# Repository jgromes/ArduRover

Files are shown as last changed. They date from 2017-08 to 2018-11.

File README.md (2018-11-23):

# ArduRover

## Open-source, full metal 6WD robot

---

Repository contents:
* **android** - All Android control app source files.
* **apk** - Android application package file. Install on your own risk!
* **arduino/arduroverController** - USB control sketch, runs on Arduino, takes in Serial input from PC and transmits the commands to the robot via LoRenz shield.
* **arduino/arduroverControllerBluetooth** - Bluetooth control sketch, same as the above but works with bluetooth and the Android control app.
* **arduino/arduroverMain** - The on-board sketch that controls the robot, receives commands via LoRenz shield and executes them.
* **doc** - Part design files (PDF drawings and Solidworks part files).

---

Find out more about the project here:
* Part 1 - <http://www.deviceplus.com/how-tos/arduino-guide/arduino-explorer-rover-chassis-final-assembly/>
* Part 2 - <http://www.deviceplus.com/how-tos/arduino-guide/arduino-explorer-rover-part-2-electronics-wiring/>
* Part 3 - <http://www.deviceplus.com/how-tos/arduino-guide/ardurover-arduino-explorer-rover-part-3-programming/>

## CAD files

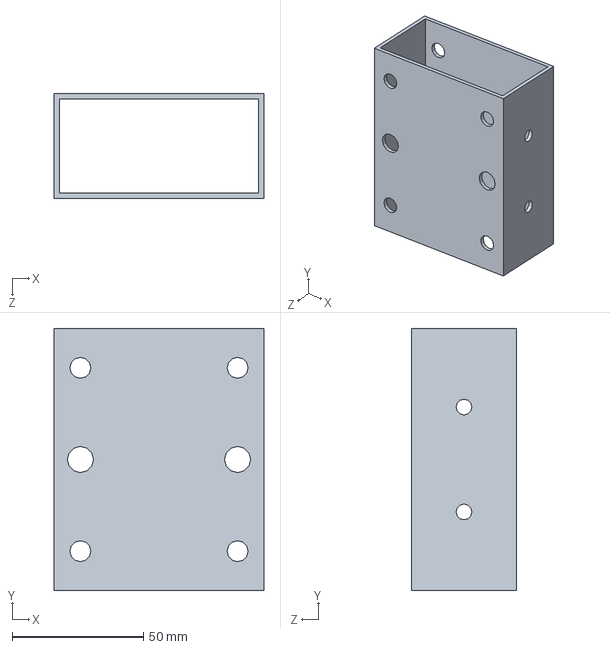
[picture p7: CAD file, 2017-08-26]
doc/sldprt/frame_block.SLDPRT
80.0 x 100.0 x 40.0 mm

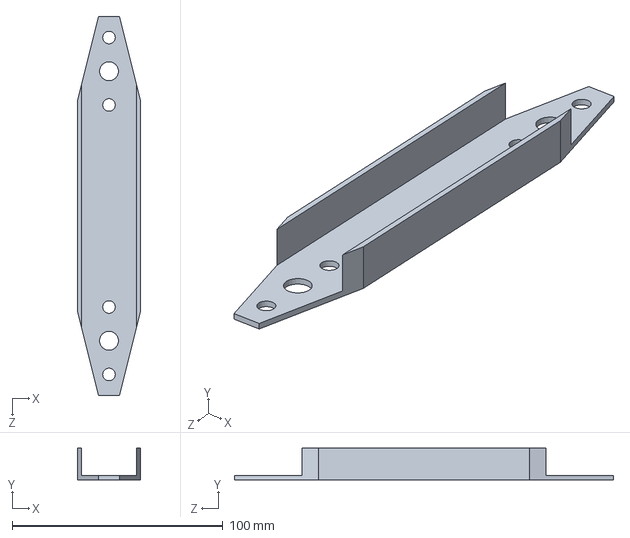
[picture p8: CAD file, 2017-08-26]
doc/sldprt/control_arm.SLDPRT
30.0 x 15.0 x 180.0 mm

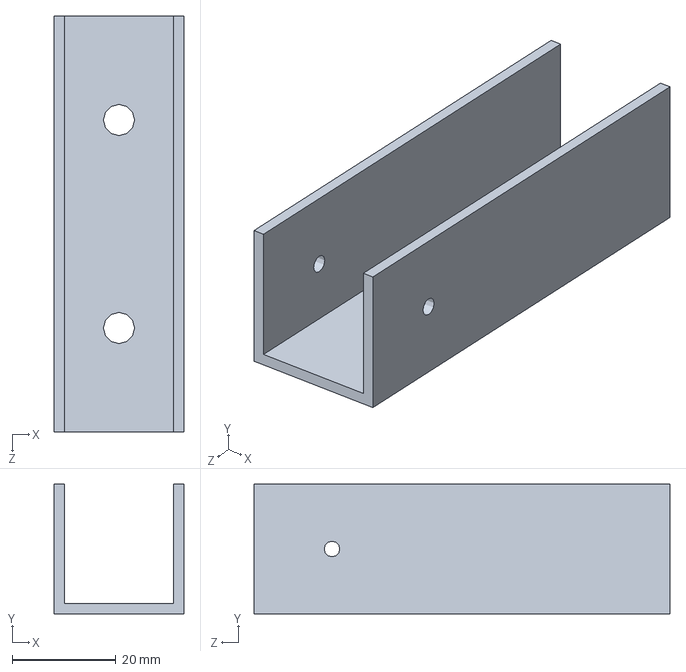
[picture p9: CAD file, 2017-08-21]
doc/sldprt/absorber_attachment_frame.SLDPRT
25.0 x 25.0 x 80.0 mm

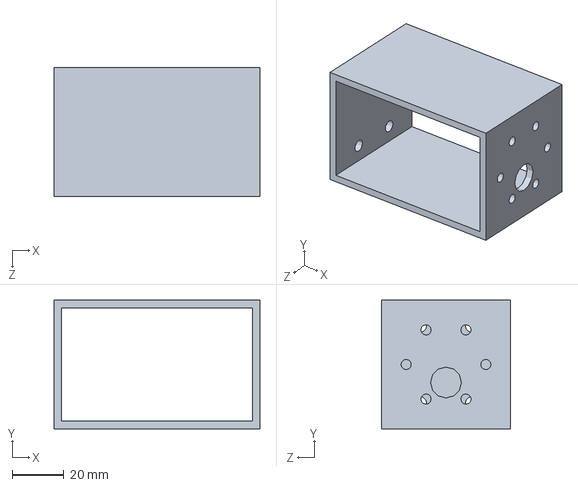
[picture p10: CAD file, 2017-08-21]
doc/sldprt/motor_block.SLDPRT
80.0 x 50.0 x 50.0 mm

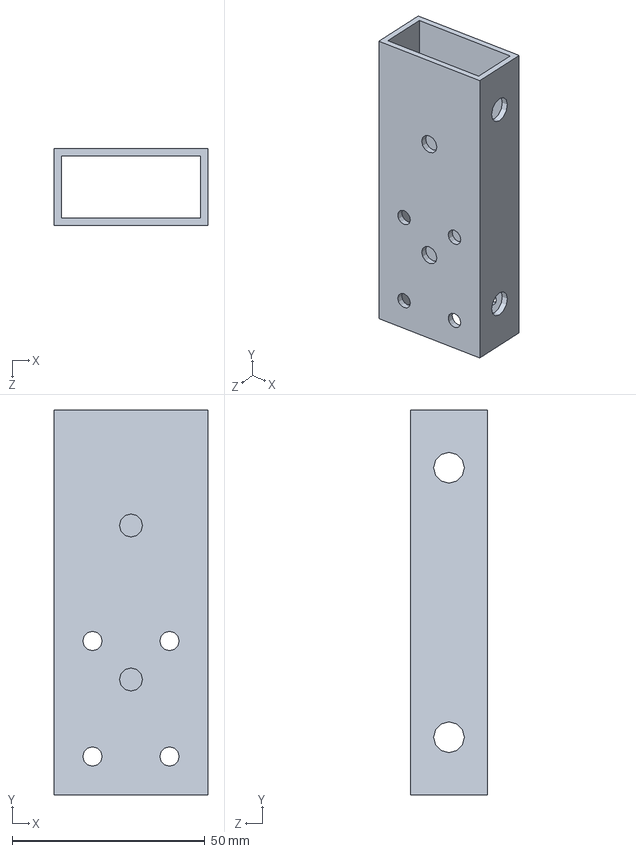
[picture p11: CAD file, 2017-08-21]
doc/sldprt/suspension_block.SLDPRT
40.0 x 100.0 x 20.0 mm

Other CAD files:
doc/sldprt/absorber_attachment_motor.SLDPRT
doc/slddrw/absorber_attachment_frame.SLDDRW
doc/slddrw/absorber_attachment_motor.SLDDRW
doc/slddrw/control_arm.SLDDRW
doc/slddrw/frame_block.SLDDRW
doc/slddrw/motor_block.SLDDRW
doc/slddrw/suspension_block.SLDDRW

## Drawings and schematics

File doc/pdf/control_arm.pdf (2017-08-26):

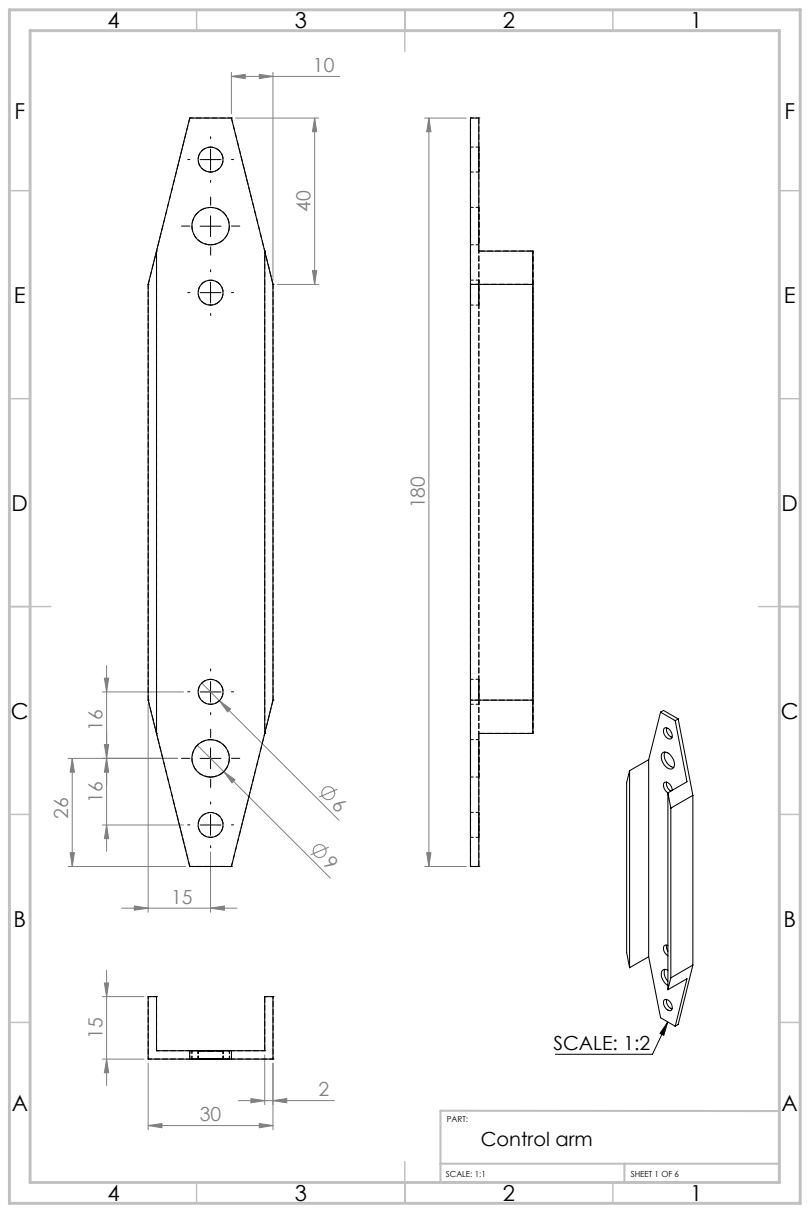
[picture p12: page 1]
SCALE: 1:2; Control arm; SCALE: 1:1; SHEET 1 OF 6

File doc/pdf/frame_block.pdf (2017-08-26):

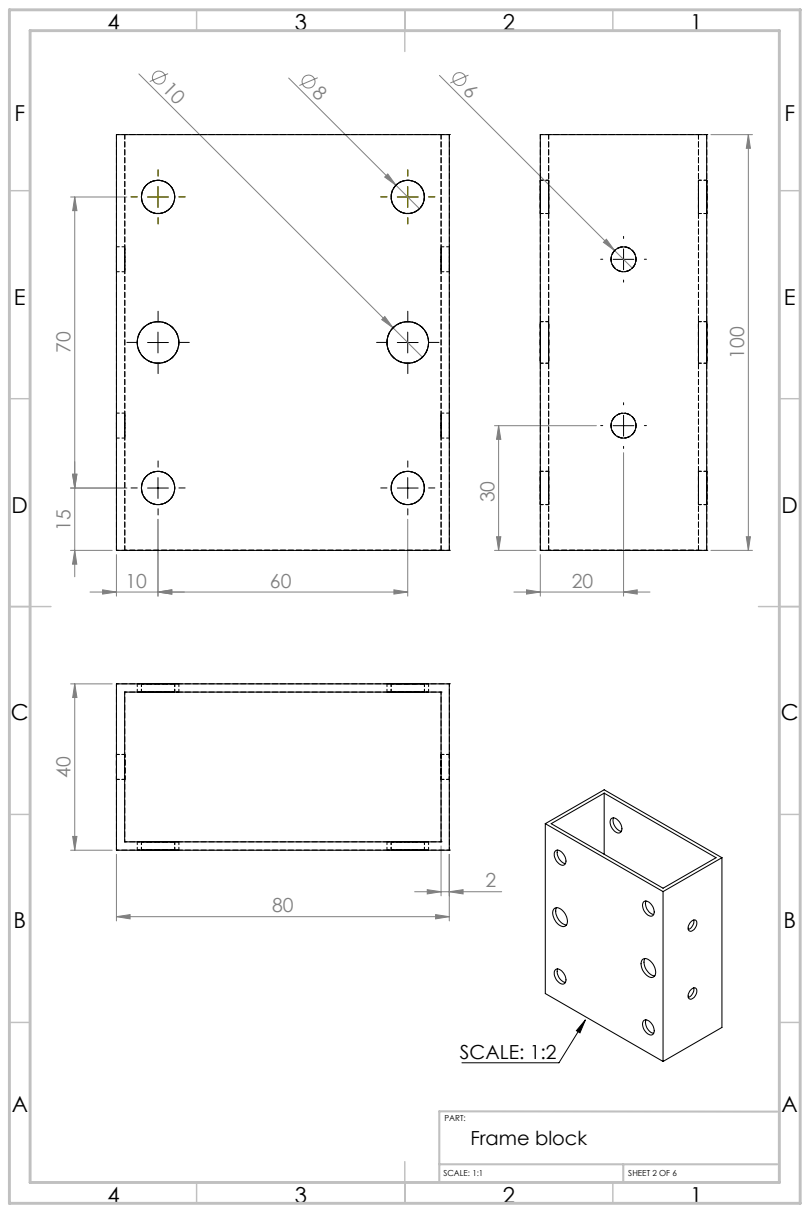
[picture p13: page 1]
SCALE: 1:2; Frame block; SCALE: 1:1; SHEET 2 OF 6

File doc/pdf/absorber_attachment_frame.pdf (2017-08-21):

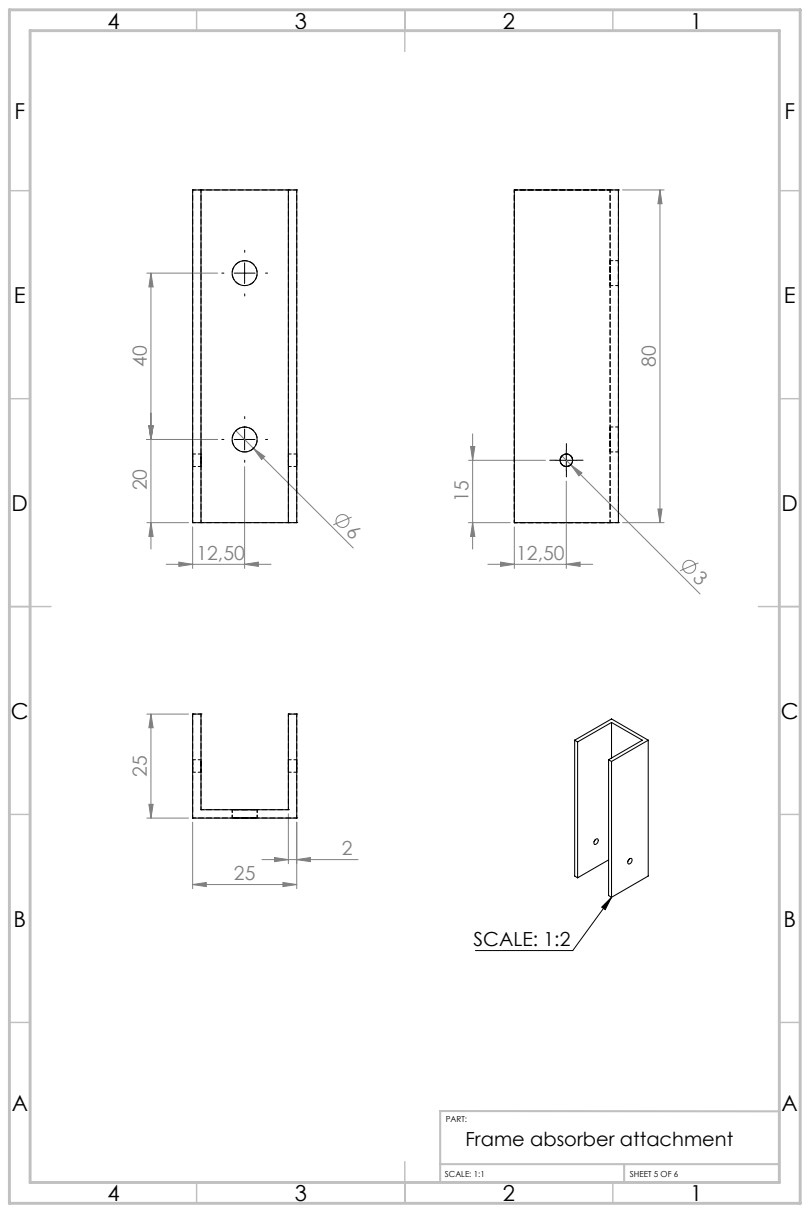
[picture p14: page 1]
SCALE: 1:2; Frame absorber attachment; SCALE: 1:1; SHEET 5 OF 6

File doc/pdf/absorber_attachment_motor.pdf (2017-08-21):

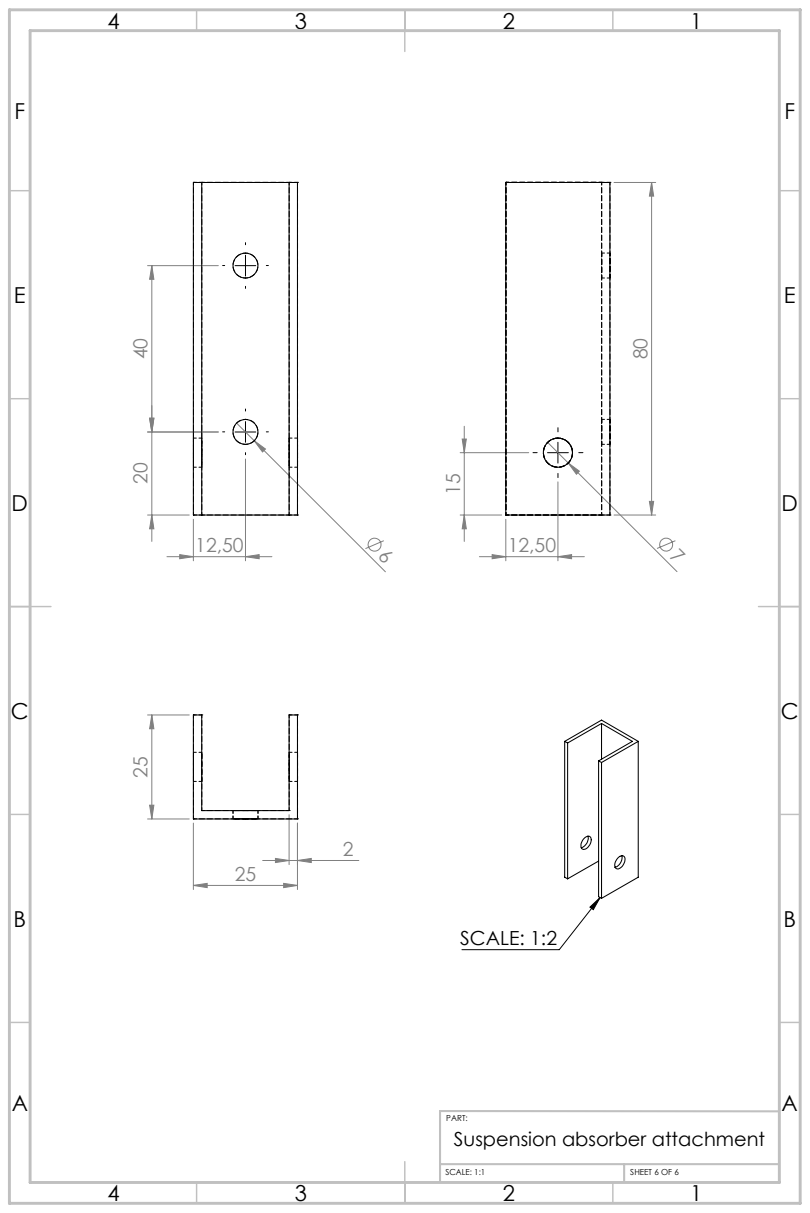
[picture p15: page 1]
SCALE: 1:2; Suspension absorber attachment; SCALE: 1:1; SHEET 6 OF 6

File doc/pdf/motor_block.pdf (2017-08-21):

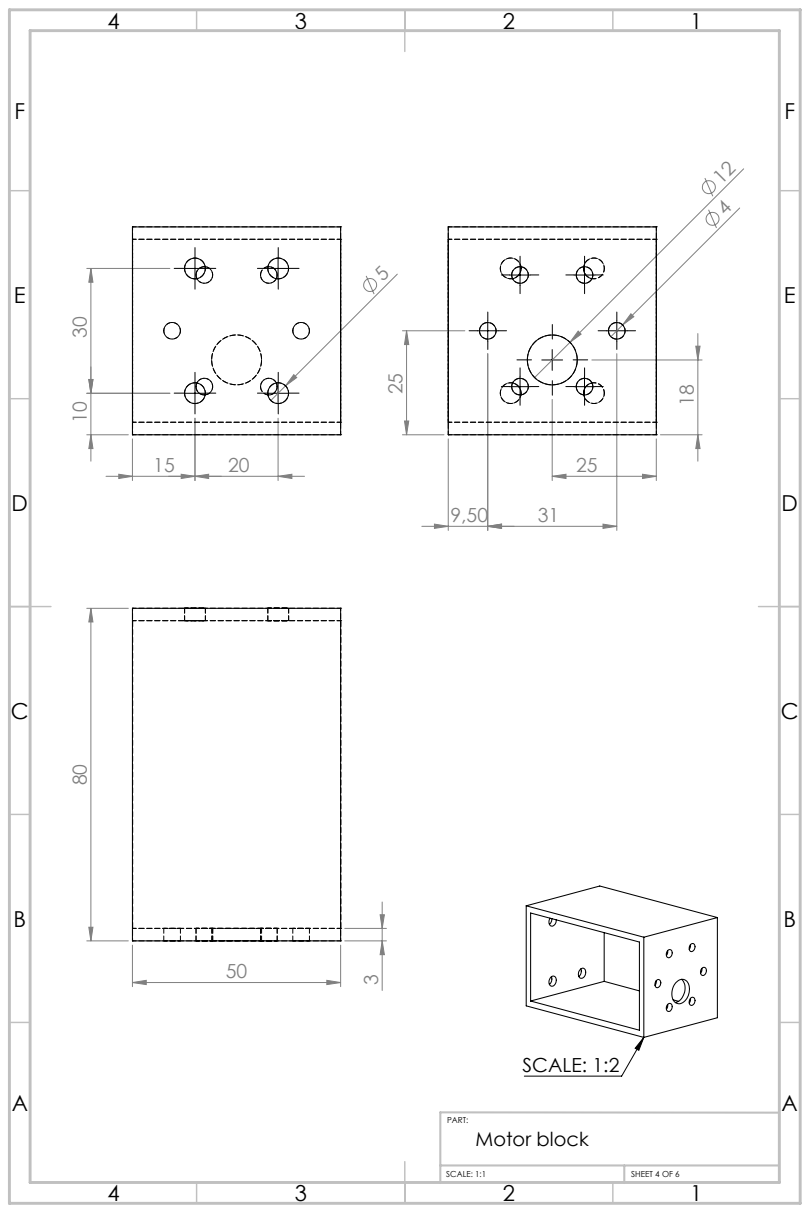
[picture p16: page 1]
SCALE: 1:2; Motor block; SCALE: 1:1; SHEET 4 OF 6

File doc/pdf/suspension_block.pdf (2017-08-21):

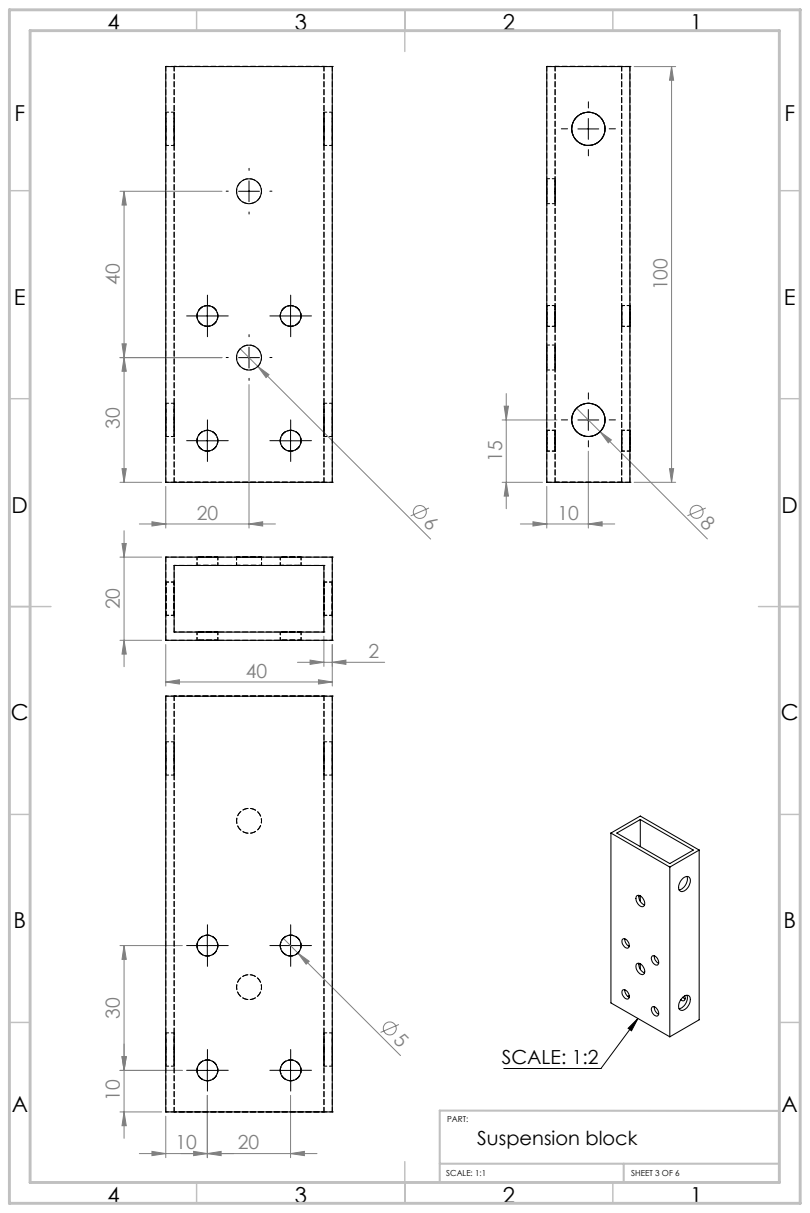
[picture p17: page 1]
SCALE: 1:2; Suspension block; SCALE: 1:1; SHEET 3 OF 6

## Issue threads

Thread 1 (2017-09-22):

Love this chasis

brandonssmith, 2017-09-22:
I found your design today and I must say I really love the idea.  I like it enough that I am going to go ahead and attempt to build my own version of it.

I am curious as to your next step as you will need to provide a base for the electronics (which I will assume with be ardurover based due to your arduino interest) and mounting points - especially keeping the power and guidance seperate.

I look forward to seeing how you progress!

jgromes, 2017-09-22:
Thanks for the feedback, I really appreciate it :)

The electronics will be mounted in the space between the suspension pairs (on the 10 mm threaded rods). Since there are two spaces available, the electronics will be mounted in the first one and battery in the second one - both inside waterproof containers. All of this will be part of my next article on http://www.deviceplus.com so keep an eye out on the site. Hopefully, it will be published within the following month.

Let me know how your build turns out!

jgromes, 2017-12-02:
The next article is up on the site ;)

Closed 2017-12-02.

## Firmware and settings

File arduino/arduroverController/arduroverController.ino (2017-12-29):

// Include LoRa library
#include <LoRaLib.h>

// Create instance of the LoRa object
LoRa lora;

// Packet to store data that will be transmitted by LoRa (commands)
uint8_t cmd[4] = {0, 0, 0, 0};
Packet out("01:23:45:67:89:AB:CD:EF", cmd, 4);

// Packet to store data that will be received by LoRa (responses)
uint8_t cmdIn[4] = {0, 0, 0, 0};
Packet in("01:23:45:67:89:AB:CD:EF", cmdIn, 4);

void setup() {
  // Begin communication via USB
  Serial.begin(9600);
  // Begin communication via LoRa
  lora.begin();
}

// This flag will be set when a packet was transmitted sucessfully 
bool sent = true;
void loop() {
  // Check if a new command was received
  if(Serial.available() > 0) {
    // Reset the flag
    sent = false;
    // Read all command bytes and store them to output buffer
    while(Serial.available()) {
      Serial.readBytes(cmd, 4);
    }
    // Copy command data to the output packet payload
    for(int i = 0; i < 4; i++) {
      out.data[i] = cmd[i];
    }
  }

  // Variable to store LoRa communication state
  uint8_t state;

  // If the current packet wasn't sent yet, send it
  if(!sent) {
    state = lora.transmit(out);
  }

  // If the packet was sent successfully, set the sent flag
  if((state == ERR_NONE) && (!sent)) {
    sent = true;
  }

  // Try to receive a packet
  state = lora.receive(in);
  if(state == ERR_NONE) {
    // If the reception was successfull, write all the response data to the USB port
    for(int i = 0; i < 4; i++) {
      Serial.write(in.data[i]);
    }

    // If the response is 0xA0, the last packet arrived malformed and has to be resend
    if(cmdIn[0] == 0xA0) {
      lora.transmit(out);
    }
  }
}

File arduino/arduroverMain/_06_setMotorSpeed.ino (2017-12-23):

// Function to set speed of one or both motors
byte setMotorSpeed(byte motor, byte pwm, byte dir) {
  switch(motor) {

    // Left side only
    case(MOTOR_LEFT): {
      // Set motor direction
      digitalWrite(MOTOR_LEFT_INA, dir);
      digitalWrite(MOTOR_LEFT_INB, dir^1);
      // Set motor speed
      analogWrite(MOTOR_LEFT_PWM, pwm);
    } break;

    // Right side only
    case(MOTOR_RIGHT): {
      // Set motor direction
      digitalWrite(MOTOR_RIGHT_INA, dir^1);
      digitalWrite(MOTOR_RIGHT_INB, dir);
      // Set motor speed
      analogWrite(MOTOR_RIGHT_PWM, pwm);
    } break;

    // Both sides
    case(MOTOR_BOTH): {
      // Set motor direction
      digitalWrite(MOTOR_LEFT_INA, dir);
      digitalWrite(MOTOR_LEFT_INB, dir^1);
      digitalWrite(MOTOR_RIGHT_INA, dir^1);
      digitalWrite(MOTOR_RIGHT_INB, dir);
      // Set motor speed
      analogWrite(MOTOR_LEFT_PWM, pwm);
      analogWrite(MOTOR_RIGHT_PWM, pwm);
    } break;
  
  }

  // Operation successful
  return(0x00);
}

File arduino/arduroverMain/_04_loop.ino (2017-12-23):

void loop() {
  //Serial.println(errFlags, BIN);

  // Check if SD card is available
  if(!(errFlags & (1 << ERR_SD_NOT_FOUND))) {
    // Check if camera is accessible
    if(errFlags & (1 << ERR_CAMERA_NOT_FOUND)) {
      // If not, try to access it again
      if(cam.begin()) {
        // If the camera was found, clear error bit
        errFlags &= ~(1 << ERR_CAMERA_NOT_FOUND);
        // Camera is a non-critical system, we can continue without it
      }
    }
    // Automatically measure all sensors
    measureSensorValues(0xFF);
    // Log sensor measurements to SD card
    logToSD();
  }

  // Wait for new LoRa packet
  byte state = lora.receive(in);

  if(state == ERR_NONE) {
    // Create a buffer to store the packet
    byte cmd[4] = {0, 0, 0, 0};

    // Empty output packet and convert input signed characters to unsigned bytes
    for(int i = 0; i < 4; i++) {
      out.data[i] = 0x00;
      cmd[i] = in.data[i] & 0xFF;
    }
    
    /*Serial.print("cmdIn:\t");
    for(int i = 0; i < 4; i++) {
      Serial.print(cmd[i], HEX);
      Serial.print('\t');
    }
    Serial.println();*/
    
    switch(cmd[0]) {

      // Stop both motors
      case(CMD_MOTOR_LR_STOP): {
        // Stop both motors and copy the result to response packet
        out.data[0] = cmd[0] | stopMotors();
      } break;

      // Set speed of both motors
      case(CMD_MOTOR_LR_SPEED): {
        // Set speed of both motors and copy the result to response packet
        out.data[0] = cmd[0] | setMotorSpeed(MOTOR_BOTH, cmd[1], cmd[2]);
      } break;

      // Set left side speed
      case(CMD_MOTOR_L_SPEED): {
        // Set left side speed and copy the result to response packet
        out.data[0] = cmd[0] | setMotorSpeed(MOTOR_LEFT, cmd[1], cmd[2]);
      } break;

      // Set right side speed
      case(CMD_MOTOR_R_SPEED): {
        // Set right side speed and copy the result to response packet
        out.data[0] = cmd[0] | setMotorSpeed(MOTOR_RIGHT, cmd[1], cmd[2]);
      } break;

      // Tilt camera
      case(CMD_CAMERA_TILT): {
        // Set tilt servo position
        setServoPosition(CAMERA_TILT, cmd[1]);
        // Copy the operation result to response packet
        out.data[0] = cmd[0] | 0x00;
      } break;

      // Pan camera
      case(CMD_CAMERA_PAN): {
        // Set pan servo position
        setServoPosition(CAMERA_PAN, cmd[1]);
        // Copy the operation result to response packet
        out.data[0] = cmd[0] | 0x00;
      } break;

      // Take a picture with the camera
      case(CMD_CAMERA_SNAP): {
        // Try to take a picture and copy the operation result to response packet
        out.data[0] = cmd[0] | takePicture();
      } break;

      // Send a picture stored on SD card
      case(CMD_CAMERA_SEND): {
        // Try to send the image and copy the operation result to response packet
        out.data[0] = cmd[0] | sendPicture(cmd[1]);
      } break;

      // Force new sensor measurement
      case(CMD_SENSOR_MEASURE): {
        // Measure the specified sensors
        out.data[0] = cmd[0] | measureSensorValues(cmd[1]);
      } break;

      // Send latest sensor data
      case(CMD_SENSOR_SEND): {
        // Send the latest data of specified sensors
        out.data[0] = cmd[0] | sendSensorValues(cmd[1]);
      } break;

      // Resend the last LoRa packet
      case(CMD_LORA_RESEND_LAST): {
        // Transmit the last packet
        lora.transmit(last);
        // Copy the operation result to response packet
        out.data[0] = cmd[0] | 0x00;
      } break;

      // Reconfigure LoRa module
      case(CMD_LORA_CONFIG): {
        out.data[0] = cmd[0];
        // Set new bandwidth, spreading factor and coding rate
        if(lora.setBandwidth(cmd[1]) == ERR_INVALID_BANDWIDTH) {
          // Specified bandwidth value is invalid
          out.data[0] |= 0x01;
        } else if(lora.setSpreadingFactor(cmd[2]) == ERR_INVALID_SPREADING_FACTOR) {
          // Specified spreading factor value is invalid
          out.data[0] |= 0x02;
        } else if(lora.setCodingRate(cmd[3]) == ERR_INVALID_CODING_RATE) {
          // Specified coding rate value is invalid
          out.data[0] |= 0x04;
        } else {
          // LoRa modem reconfiguration successful
          out.data[0] |= 0x00;
        }
      } break;

      // Send error flags
      case(CMD_LORA_REQUEST_ERRORS): {
        // Copy error flags to response packet
        out.data[1] = (errFlags >> 8) & 0xFF;
        out.data[2] = errFlags & 0xFF;
        // Copy the operation result to response packet
        out.data[0] = cmd[0] | 0x00;
      } break;
    }

    /*Serial.print("cmdOut:\t");
    for(int i = 0; i < 4; i++) {
      Serial.print(out.data[i], HEX);
      Serial.print('\t');
    }
    Serial.println();*/

    // Transmit response packet
    lora.transmit(out);

    // Copy the response packet in case it needs to be resend
    out.copyInto(last);
    
  } else if(state == ERR_CRC_MISMATCH) {
    // If the received packet was damaged, request a resend
    out.data[0] = CMD_LORA_RESEND_LAST;
    lora.transmit(out);
  }
}

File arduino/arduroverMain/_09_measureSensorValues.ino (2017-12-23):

// Function to measure values of specified sensor(s)
byte measureSensorValues(byte sen) {
  // Variable to store status of the current sensor
  byte state;

  // Response variable
  byte response = 0x00;

  // BM1422GMV measurement was requested
  if((sen >> 0) & 1) {
    // Measure sensor
    state = sensorMag.measure();
    // Copy the operation result into response variable
    response |= state << 0;
    // Update error flags
    setBit(&errFlags, ERR_SENSOR_BM1422GMV, state);
    if(state == 0) {
      // Measurement was successful, update measurement variables
      magneticX.number = sensorMag.magX;
      magneticY.number = sensorMag.magY;
      magneticZ.number = sensorMag.magZ;
    }

  // RPR-0521RS measurement was requested
  } else if((sen >> 1) & 1) {
    // Measure sensor
    state = sensorAls.measure();
    // Copy the operation result into response variable
    response |= state << 1;
    // Update error flags
    setBit(&errFlags, ERR_SENSOR_RPR_0521RS, state);
    if(state == 0) {
      // Measurement was successful, update measurement variables
      proximity.number = sensorAls.prox;
      ambientLight.number = sensorAls.ambLight;
    }

  // KX022-1020 measurement was requested
  } else if((sen >> 2) & 1) {
    // Measure sensor
    state = sensorAcc.measure();
    // Copy the operation result into response variable
    response |= state << 2;
    // Update error flags
    setBit(&errFlags, ERR_SENSOR_KX022_1020, state);
    if(state == 0) {
      // Measurement was successful, update measurement variables
      accelerationX.number = sensorAcc.accelX;
      accelerationY.number = sensorAcc.accelY;
      accelerationZ.number = sensorAcc.accelZ;
    }

  // BM1383GLV measurement was requested
  } else if((sen >> 3) & 1) {
    // Measure sensor
    state = sensorPress.measure();
    // Copy the operation result into response variable
    response |= state << 3;
    // Update error flags
    setBit(&errFlags, ERR_SENSOR_BM1383GLV, state);
    if(state == 0) {
      // Measurement was successful, update measurement variable
      pressure.number = sensorPress.pres;
    }

  // ML8511A measurement was requested
  } else if((sen >> 4) & 1) {
    // Measure sensor
    state = sensorUV.measure();
    // Copy the operation result into response variable
    response |= state << 4;
    // Update error flags
    setBit(&errFlags, ERR_SENSOR_ML8511, state);
    if(state == 0) {
      // Measurement was successful, update measurement variable
      uvRadiation.number = sensorUV.uvRad;
    }

  // BD1020HFV measurement was requested
  } else if((sen >> 5) & 1) {
    // Measure sensor
    state = sensorTmp.measure();
    // Copy the operation result into response variable
    response |= state << 5;
    // Update error flags
    setBit(&errFlags, ERR_SENSOR_BD1020HFV, state);
    if(state == 0) {
      // Measurement was successful, update measurement variable
      temperature.number = sensorTmp.temp;
    }

  // Left motor current measurement was requested
  } else if((sen >> 6) & 1) {
    // Measure current of left side motors and update the measurement variable
    currentLeft.number = analogRead(MOTOR_LEFT_CS);
    // Copy the operation result into response variable
    response |= 0x00 << 6;

  // Right motor current measurement was requested
  } else if((sen >> 7) & 1) {
    // Measure current of left side motors and update the measurement variable
    currentRight.number = analogRead(MOTOR_RIGHT_CS);
    // Copy the operation result into response variable
    response |= 0x00 << 7;
  }

  // Return operation status
  return(response);
}

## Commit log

2017-08-21 Fixed control arm drawing
2017-08-21 Added SolidWorks files
    [absorber_attachment_frame.SLDDRW, absorber_attachment_frame.SLDPRT, absorber_attachment_motor.SLDDRW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]
2017-08-25 Fixed control arm dimensions
    [control_arm.SLDDRW, control_arm.SLDPRT]
2017-08-26 Fixed hole diameter
    [control_arm.SLDDRW, control_arm.SLDPRT, frame_block.SLDDRW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]
2017-12-15 Added Arduino sketches
2017-12-23 Added Arduino sketch for Bluetooth control
2017-12-23 Updated on-board Arduino sketch
